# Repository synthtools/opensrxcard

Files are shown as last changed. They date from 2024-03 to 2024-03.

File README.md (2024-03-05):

# opensrxcard
opensrxcard is an open source SRX card project that consists of 
- An SRX card that can be used in Roland devices like the Fantom X/XR (other 5V devices like XV5080/XV3080 etc. in the future)
- An Arudino Due based programmer that allows to dump, program and erase SRX cards.





This is work in progress. Keep watching.

# Further information and documentation
Please go to the [wiki for detailed documentation](https://github.com/synthtools/opensrxcard/wiki).

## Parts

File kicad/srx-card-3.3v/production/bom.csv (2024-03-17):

Designator | Footprint | Quantity | Value | LCSC Part #
C1, C3, C7, C8 | 0805 | 4 | 100nF | C710699
C10 | CP_EIA-3528-21_Kemet-B_Pad1.50x2.35mm_HandSolder | 1 | Tantalum J106 10uF | C110050
C2, C4 | 0805 | 2 | 10nF | C161252
C9 | CP_EIA-3528-21_Kemet-B_Pad1.50x2.35mm_HandSolder | 1 | Tantalum J106 10uF | C110050
IC1, IC2 | TSOP-I-56_18.4x14mm_P0.5mm | 2 | MT28EW128ABA | C598856
R1 | 0805 | 1 | 100k | C122537
R2, R3, R4, R5 | 0805 | 4 | 10k | C441955

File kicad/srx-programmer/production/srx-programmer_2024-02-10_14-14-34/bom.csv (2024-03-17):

Designator | Footprint | Quantity | Value | LCSC Part #
C1 | CP_EIA-3216-12_Kemet-S_Pad1.58x1.35mm_HandSolder | 1 | Tantalum J104 0.1uF
J1 | PinHeader_1x08_P2.54mm_Vertical | 1 | Power
J2 | PinHeader_1x10_P2.54mm_Vertical | 1 | PWM
J3, J5 | PinHeader_1x08_P2.54mm_Vertical | 2 | Analog
J4 | PinHeader_1x08_P2.54mm_Vertical | 1 | PWM
J6 | PinHeader_1x08_P2.54mm_Vertical | 1 | Communication
J7 | PinHeader_2x18_P2.54mm_Vertical | 1 | Digital
J8 | JAE_TX25-80P-6ST-H1E | 1 | TX25-80P-6ST-H1E
J9 | PinHeader_2x02_P2.54mm_Vertical | 1 | Secondary Programming Connector
SW1, SW2, SW3 | SW_PUSH_6mm | 3 | SW_Push

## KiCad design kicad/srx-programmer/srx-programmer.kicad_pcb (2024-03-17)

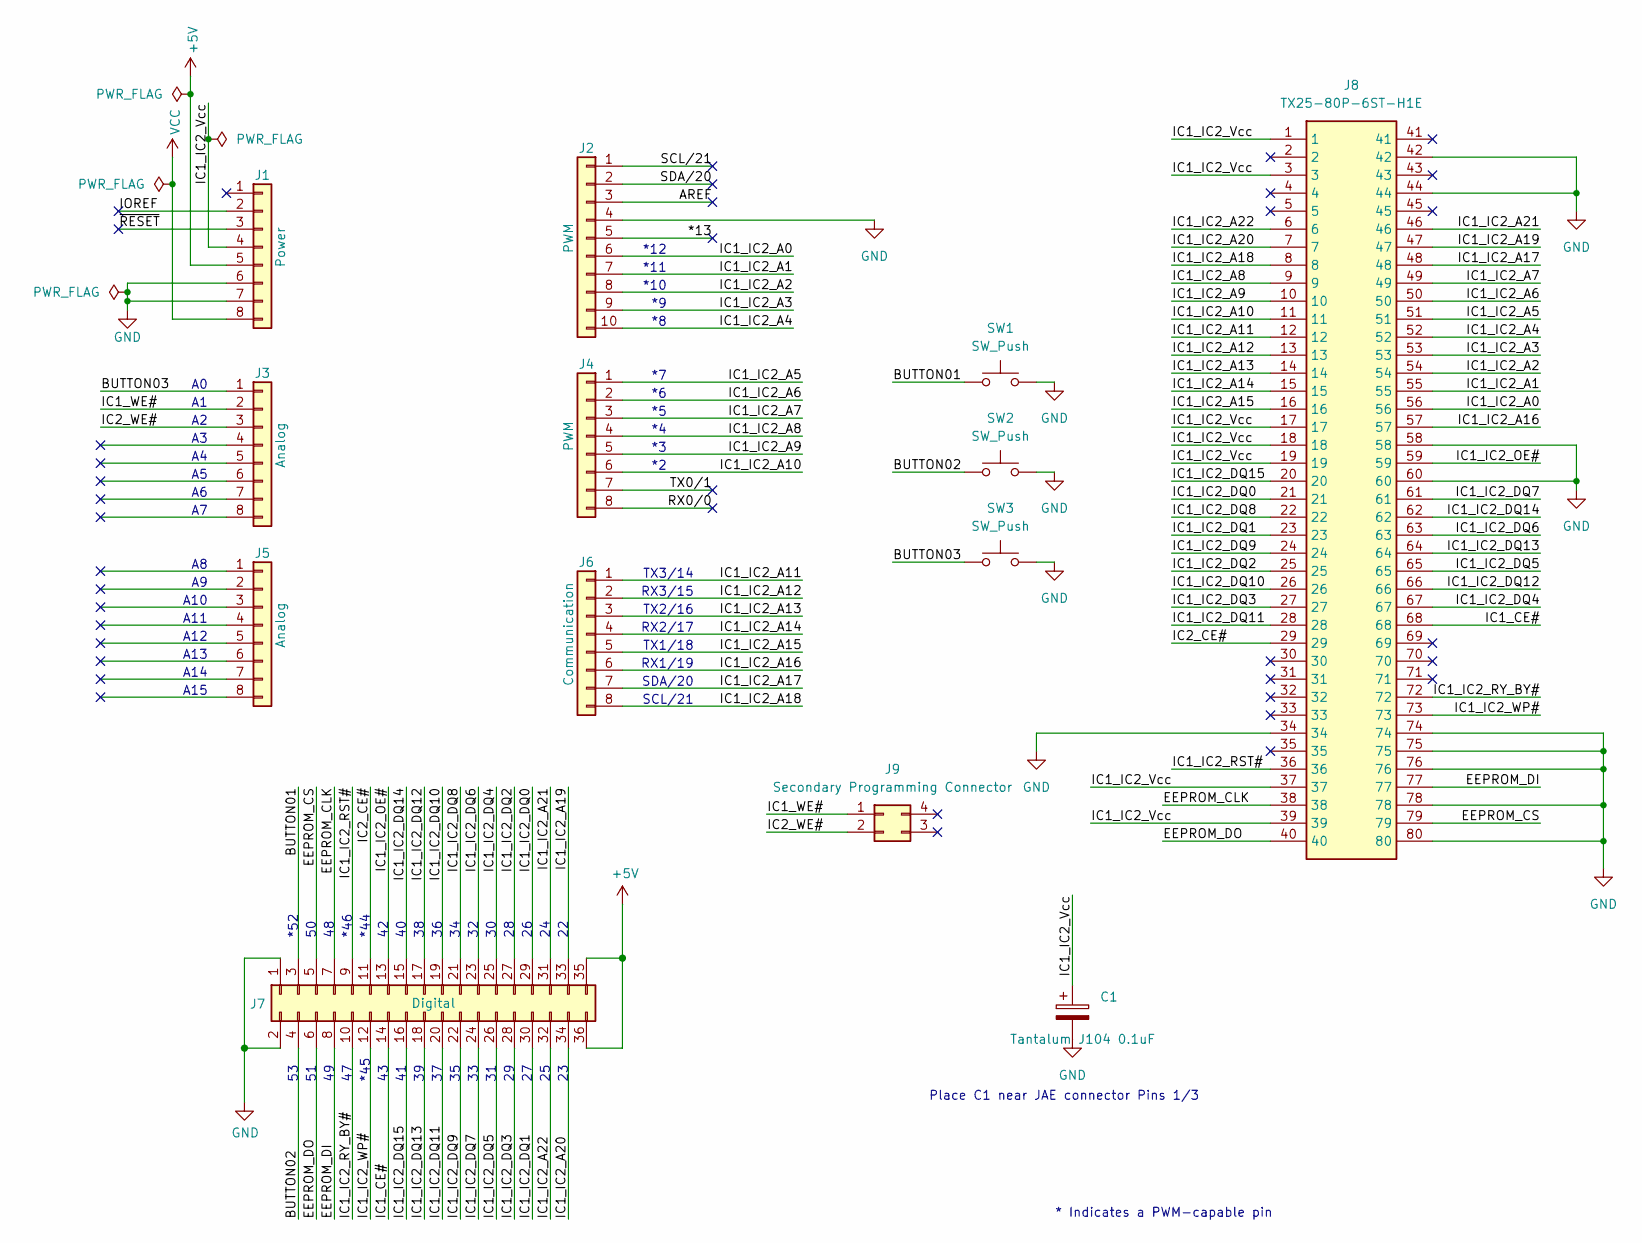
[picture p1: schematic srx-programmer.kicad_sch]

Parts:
C1: Tantalum J104 0.1uF; CP_EIA-3216-12_Kemet-S_Pad1.58x1.35mm_HandSolder
J1: Power; PinHeader_1x08_P2.54mm_Vertical
J2: PWM; PinHeader_1x10_P2.54mm_Vertical
J3, J5: Analog; PinHeader_1x08_P2.54mm_Vertical
J4: PWM; PinHeader_1x08_P2.54mm_Vertical
J6: Communication; PinHeader_1x08_P2.54mm_Vertical
J7: Digital; PinHeader_2x18_P2.54mm_Vertical
J8: TX25-80P-6ST-H1E; JAE_TX25-80P-6ST-H1E; Mouser Part Number 656-TX2580P6STH1E
J9: Secondary Programming Connector; PinHeader_2x02_P2.54mm_Vertical
SW1, SW2, SW3: SW_Push; SW_PUSH_6mm

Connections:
+5V: J1.5, J7.35, J7.36
/*13: J2.5
/AREF: J2.3
/BUTTON01: J7.3, SW1.1
/BUTTON02: J7.4, SW2.1
/BUTTON03: J3.1, SW3.1
/EEPROM_CLK: J7.7, J8.38
/EEPROM_CS: J7.5, J8.79
/EEPROM_DI: J7.8, J8.77
/EEPROM_DO: J7.6, J8.40
/IC1_CE#: J7.14, J8.68
/IC1_IC2_A0: J2.6, J8.56
/IC1_IC2_A1: J2.7, J8.55
/IC1_IC2_A2: J2.8, J8.54
/IC1_IC2_A3: J2.9, J8.53
/IC1_IC2_A4: J2.10, J8.52
/IC1_IC2_A5: J4.1, J8.51
/IC1_IC2_A6: J4.2, J8.50
/IC1_IC2_A7: J4.3, J8.49
/IC1_IC2_A8: J4.4, J8.9
/IC1_IC2_A9: J4.5, J8.10
/IC1_IC2_A10: J4.6, J8.11
/IC1_IC2_A11: J6.1, J8.12
/IC1_IC2_A12: J6.2, J8.13
/IC1_IC2_A13: J6.3, J8.14
/IC1_IC2_A14: J6.4, J8.15
/IC1_IC2_A15: J6.5, J8.16
/IC1_IC2_A16: J6.6, J8.57
/IC1_IC2_A17: J6.7, J8.48
/IC1_IC2_A18: J6.8, J8.8
/IC1_IC2_A19: J7.33, J8.47
/IC1_IC2_A20: J7.34, J8.7
/IC1_IC2_A21: J7.31, J8.46
/IC1_IC2_A22: J7.32, J8.6
/IC1_IC2_DQ0: J7.29, J8.21
/IC1_IC2_DQ1: J7.30, J8.23
/IC1_IC2_DQ2: J7.27, J8.25
/IC1_IC2_DQ3: J7.28, J8.27
/IC1_IC2_DQ4: J7.25, J8.67
/IC1_IC2_DQ5: J7.26, J8.65
/IC1_IC2_DQ6: J7.23, J8.63
/IC1_IC2_DQ7: J7.24, J8.61
/IC1_IC2_DQ8: J7.21, J8.22
/IC1_IC2_DQ9: J7.22, J8.24
/IC1_IC2_DQ10: J7.19, J8.26
/IC1_IC2_DQ11: J7.20, J8.28
/IC1_IC2_DQ12: J7.17, J8.66
/IC1_IC2_DQ13: J7.18, J8.64
/IC1_IC2_DQ14: J7.15, J8.62
/IC1_IC2_DQ15: J7.16, J8.20
/IC1_IC2_OE#: J7.13, J8.59
/IC1_IC2_RST#: J7.9, J8.36
/IC1_IC2_RY_BY#: J7.10, J8.72
/IC1_IC2_Vcc: C1.1, J1.4, J8.1, J8.3, J8.17, J8.18, J8.19, J8.37, J8.39
/IC1_IC2_WP#: J7.12, J8.73
/IC1_WE#: J3.2, J9.1
/IC2_CE#: J7.11, J8.29
/IC2_WE#: J3.3, J9.2
/IOREF: J1.2
/RX0/0: J4.8
/SCL/21: J2.1
/SDA/20: J2.2
/TX0/1: J4.7
/~RESET: J1.3
GND: C1.2, J1.6, J1.7, J2.4, J7.1, J7.2, J8.34, J8.42, J8.44, J8.58, J8.60, J8.74, J8.75, J8.76, J8.78, J8.80, SW1.2, SW2.2, SW3.2
VCC: J1.8

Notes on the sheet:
TX1/18
RX2/17
*12
SCL/21
TX2/16
A11
*44
RX3/15
*45
A10
A12
SDA/20
RX1/19
*11
Place C1 near JAE connector Pins 1/3
* Indicates a PWM-capable pin
*46
A15
*10
A14
A13
*52
TX3/14

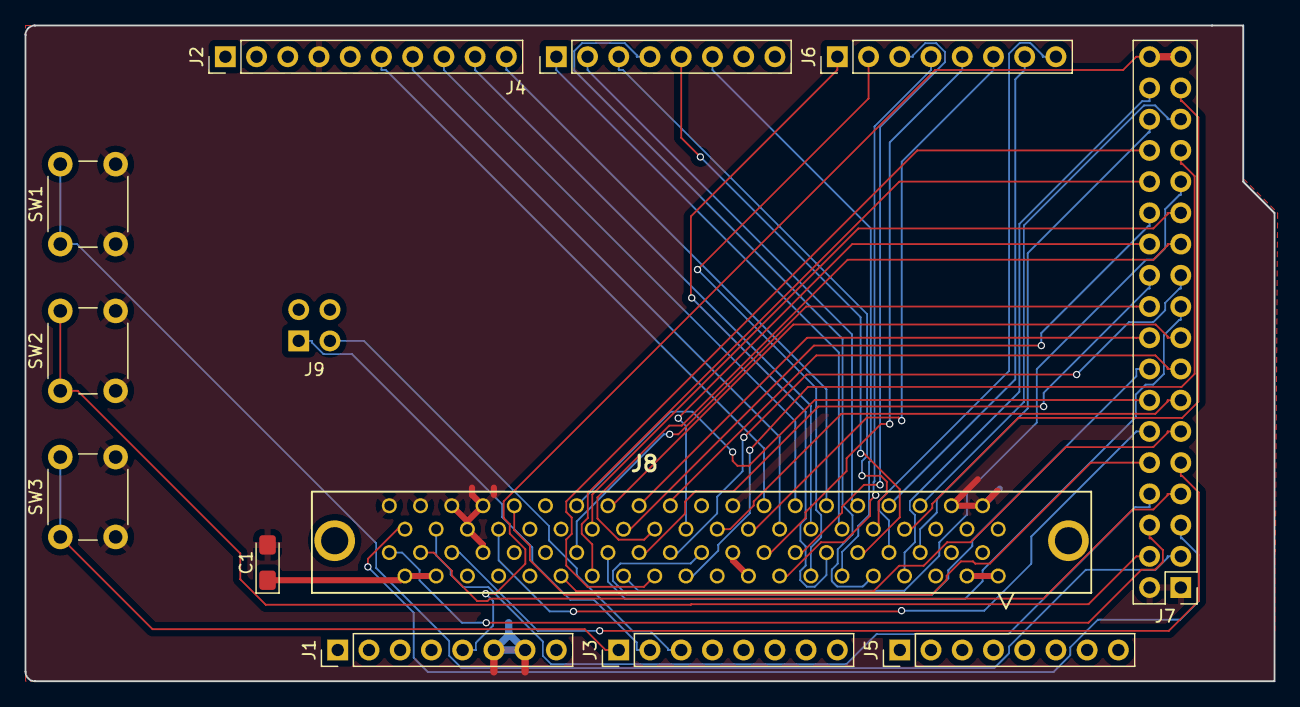
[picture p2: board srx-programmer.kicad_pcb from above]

Board: 4 copper layers, 101.6 x 53.3 mm, 13 parts (1 on the bottom side), 57 nets.

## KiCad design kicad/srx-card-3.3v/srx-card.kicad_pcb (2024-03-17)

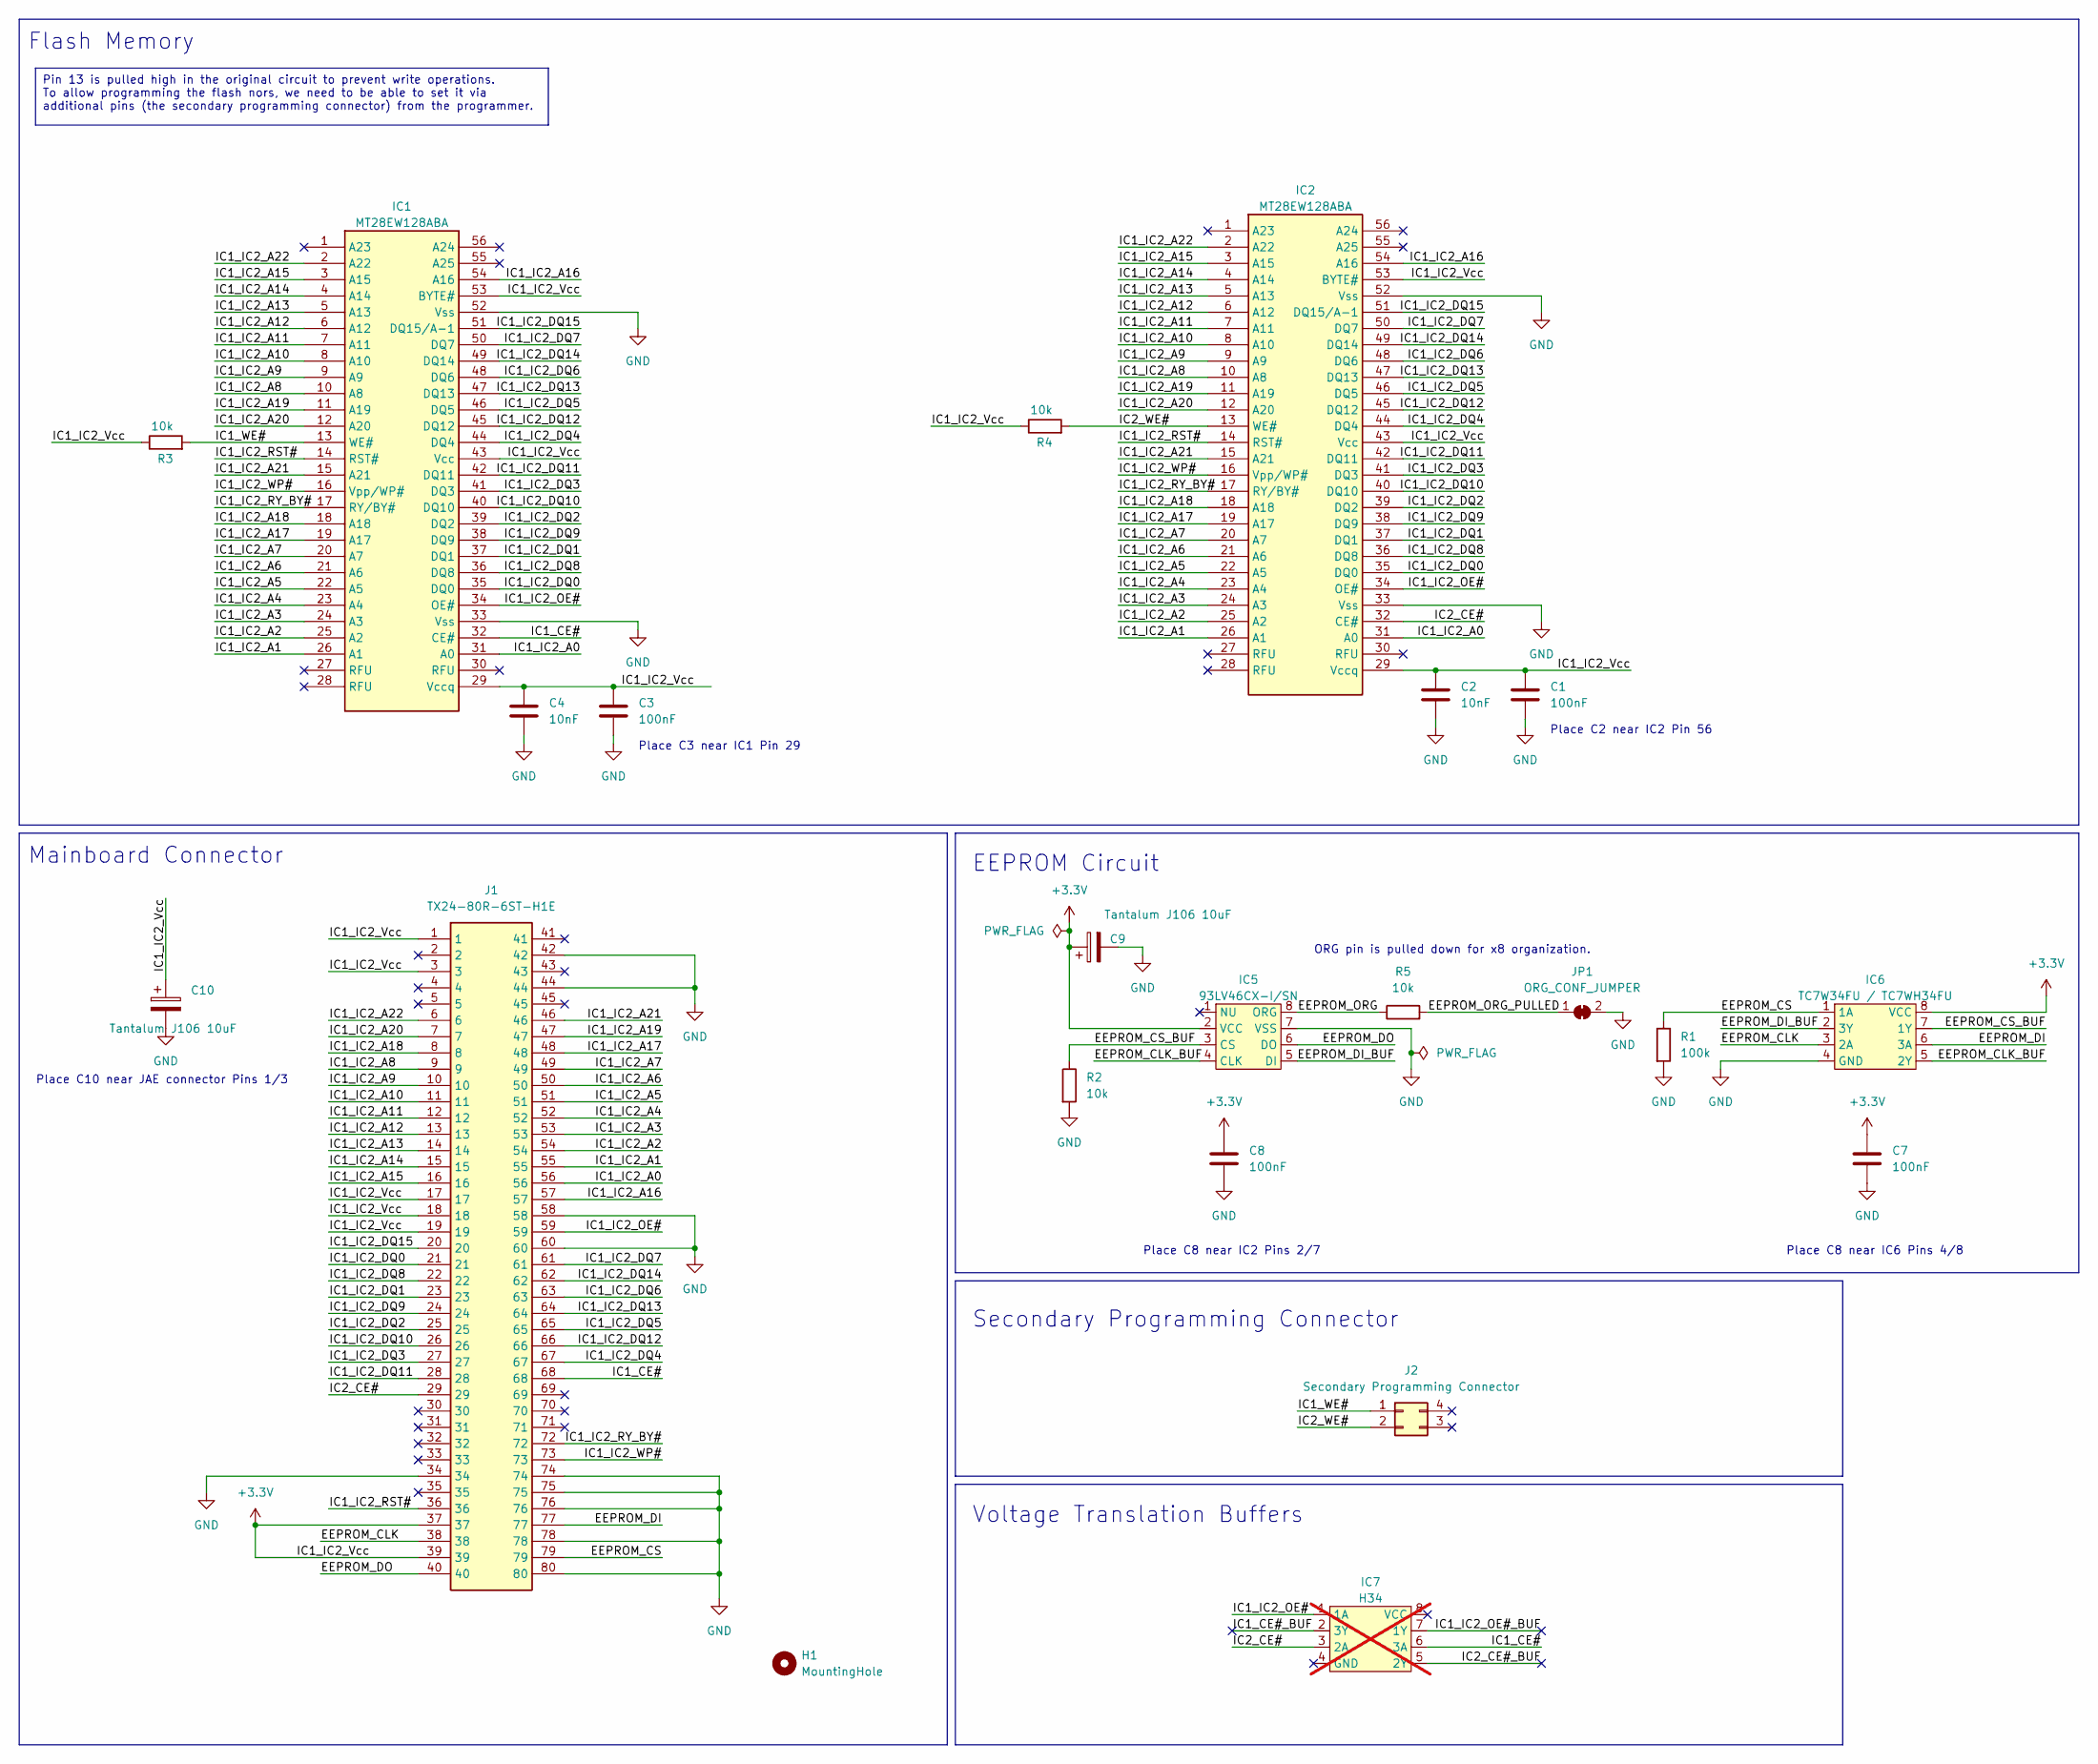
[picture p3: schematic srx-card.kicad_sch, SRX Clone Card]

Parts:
C1, C3, C7, C8: 100nF; C_0805_2012Metric_Pad1.18x1.45mm_HandSolder; LCSC C710699
C2, C4: 10nF; C_0805_2012Metric_Pad1.18x1.45mm_HandSolder; LCSC C161252
C9, C10: Tantalum J106 10uF; CP_EIA-3528-21_Kemet-B_Pad1.50x2.35mm_HandSolder; LCSC C110050
H1: MountingHole; MountingHole_5mm
IC1, IC2: MT28EW128ABA; TSOP-I-56_18.4x14mm_P0.5mm; LCSC C598856
IC5: 93LV46CX-I/SN; SOIC-8_3.9x4.9mm_P1.27mm
IC6: TC7W34FU / TC7WH34FU; SSOP-8_2.95x2.8mm_P0.65mm; LCSC C2676253
IC7: H34; SSOP-8_2.95x2.8mm_P0.65mm; not fitted
J1: TX24-80R-6ST-H1E; JAE_TX24-80R-6ST-H1E; Mouser Part Number 656-TX24-80R-6ST-H1E
J2: Secondary Programming Connector; PinHeader_2x02_P2.54mm_Vertical
JP1: ORG_CONF_JUMPER; SolderJumper-2_P1.3mm_Bridged_Pad1.0x1.5mm
R1: 100k; R_0805_2012Metric_Pad1.20x1.40mm_HandSolder; LCSC C122537
R2, R3, R4, R5: 10k; R_0805_2012Metric_Pad1.20x1.40mm_HandSolder; LCSC C441955

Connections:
+3.3V: C1.1, C2.1, C3.1, C4.1, C7.1, C8.1, C9.1, C10.1, IC1.29 (Vccq), IC1.43 (Vcc), IC1.53 (BYTE#), IC2.29 (Vccq), IC2.43 (Vcc), IC2.53 (BYTE#), IC5.2 (VCC), IC6.8 (VCC), J1.1, J1.3, J1.17, J1.18, J1.19, J1.37, J1.39, R3.1, R4.1
/EEPROM_CLK: IC6.3 (2A), J1.38
/EEPROM_CLK_BUF: IC5.4 (CLK), IC6.5 (2Y)
/EEPROM_CS: IC6.1 (1A), J1.79, R1.1
/EEPROM_CS_BUF: IC5.3 (CS), IC6.7 (1Y), R2.1
/EEPROM_DI: IC6.6 (3A), J1.77
/EEPROM_DI_BUF: IC5.5 (DI), IC6.2 (3Y)
/EEPROM_DO: IC5.6 (DO), J1.40
/EEPROM_ORG: IC5.8 (ORG), R5.1
/EEPROM_ORG_PULLED: JP1.1 (A), R5.2
/IC1_CE#: IC1.32 (CE#), IC7.6 (3A), J1.68
/IC1_IC2_A0: IC1.31 (A0), IC2.31 (A0), J1.56
/IC1_IC2_A1: IC1.26 (A1), IC2.26 (A1), J1.55
/IC1_IC2_A2: IC1.25 (A2), IC2.25 (A2), J1.54
/IC1_IC2_A3: IC1.24 (A3), IC2.24 (A3), J1.53
/IC1_IC2_A4: IC1.23 (A4), IC2.23 (A4), J1.52
/IC1_IC2_A5: IC1.22 (A5), IC2.22 (A5), J1.51
/IC1_IC2_A6: IC1.21 (A6), IC2.21 (A6), J1.50
/IC1_IC2_A7: IC1.20 (A7), IC2.20 (A7), J1.49
/IC1_IC2_A8: IC1.10 (A8), IC2.10 (A8), J1.9
/IC1_IC2_A9: IC1.9 (A9), IC2.9 (A9), J1.10
/IC1_IC2_A10: IC1.8 (A10), IC2.8 (A10), J1.11
/IC1_IC2_A11: IC1.7 (A11), IC2.7 (A11), J1.12
/IC1_IC2_A12: IC1.6 (A12), IC2.6 (A12), J1.13
/IC1_IC2_A13: IC1.5 (A13), IC2.5 (A13), J1.14
/IC1_IC2_A14: IC1.4 (A14), IC2.4 (A14), J1.15
/IC1_IC2_A15: IC1.3 (A15), IC2.3 (A15), J1.16
/IC1_IC2_A16: IC1.54 (A16), IC2.54 (A16), J1.57
/IC1_IC2_A17: IC1.19 (A17), IC2.19 (A17), J1.48
/IC1_IC2_A18: IC1.18 (A18), IC2.18 (A18), J1.8
/IC1_IC2_A19: IC1.11 (A19), IC2.11 (A19), J1.47
/IC1_IC2_A20: IC1.12 (A20), IC2.12 (A20), J1.7
/IC1_IC2_A21: IC1.15 (A21), IC2.15 (A21), J1.46
/IC1_IC2_A22: IC1.2 (A22), IC2.2 (A22), J1.6
/IC1_IC2_DQ0: IC1.35 (DQ0), IC2.35 (DQ0), J1.21
/IC1_IC2_DQ1: IC1.37 (DQ1), IC2.37 (DQ1), J1.23
/IC1_IC2_DQ2: IC1.39 (DQ2), IC2.39 (DQ2), J1.25
/IC1_IC2_DQ3: IC1.41 (DQ3), IC2.41 (DQ3), J1.27
/IC1_IC2_DQ4: IC1.44 (DQ4), IC2.44 (DQ4), J1.67
/IC1_IC2_DQ5: IC1.46 (DQ5), IC2.46 (DQ5), J1.65
/IC1_IC2_DQ6: IC1.48 (DQ6), IC2.48 (DQ6), J1.63
/IC1_IC2_DQ7: IC1.50 (DQ7), IC2.50 (DQ7), J1.61
/IC1_IC2_DQ8: IC1.36 (DQ8), IC2.36 (DQ8), J1.22
/IC1_IC2_DQ9: IC1.38 (DQ9), IC2.38 (DQ9), J1.24
/IC1_IC2_DQ10: IC1.40 (DQ10), IC2.40 (DQ10), J1.26
/IC1_IC2_DQ11: IC1.42 (DQ11), IC2.42 (DQ11), J1.28
/IC1_IC2_DQ12: IC1.45 (DQ12), IC2.45 (DQ12), J1.66
/IC1_IC2_DQ13: IC1.47 (DQ13), IC2.47 (DQ13), J1.64
/IC1_IC2_DQ14: IC1.49 (DQ14), IC2.49 (DQ14), J1.62
/IC1_IC2_DQ15: IC1.51 (DQ15/A-1), IC2.51 (DQ15/A-1), J1.20
/IC1_IC2_OE#: IC1.34 (OE#), IC2.34 (OE#), IC7.1 (1A), J1.59
/IC1_IC2_RST#: IC1.14 (RST#), IC2.14 (RST#), J1.36
/IC1_IC2_RY_BY#: IC1.17 (RY/BY#), IC2.17 (RY/BY#), J1.72
/IC1_IC2_WP#: IC1.16 (Vpp/WP#), IC2.16 (Vpp/WP#), J1.73
/IC1_WE#: IC1.13 (WE#), J2.1, R3.2
/IC2_CE#: IC2.32 (CE#), IC7.3 (2A), J1.29
/IC2_WE#: IC2.13 (WE#), J2.2, R4.2
GND: C1.2, C2.2, C3.2, C4.2, C7.2, C8.2, C9.2, C10.2, IC1.33 (Vss), IC1.52 (Vss), IC2.33 (Vss), IC2.52 (Vss), IC5.7 (VSS), IC6.4 (GND), J1.34, J1.42, J1.44, J1.58, J1.60, J1.74, J1.75, J1.76, J1.78, J1.80, JP1.2 (B), R1.2, R2.2

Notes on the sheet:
Pin 13 is pulled high in the original circuit to prevent write operations. To allow programming the flash nors, we need to be able to set it via additional pins (the secondary programming connector) from the programmer.
Flash Memory
Place C3 near IC1 Pin 29
Place C10 near JAE connector Pins 1/3
Place C2 near IC2 Pin 56
ORG pin is pulled down for x8 organization.
Voltage Translation Buffers
EEPROM Circuit
Place C8 near IC6 Pins 4/8
Place C8 near IC2 Pins 2/7
Secondary Programming Connector
Mainboard Connector

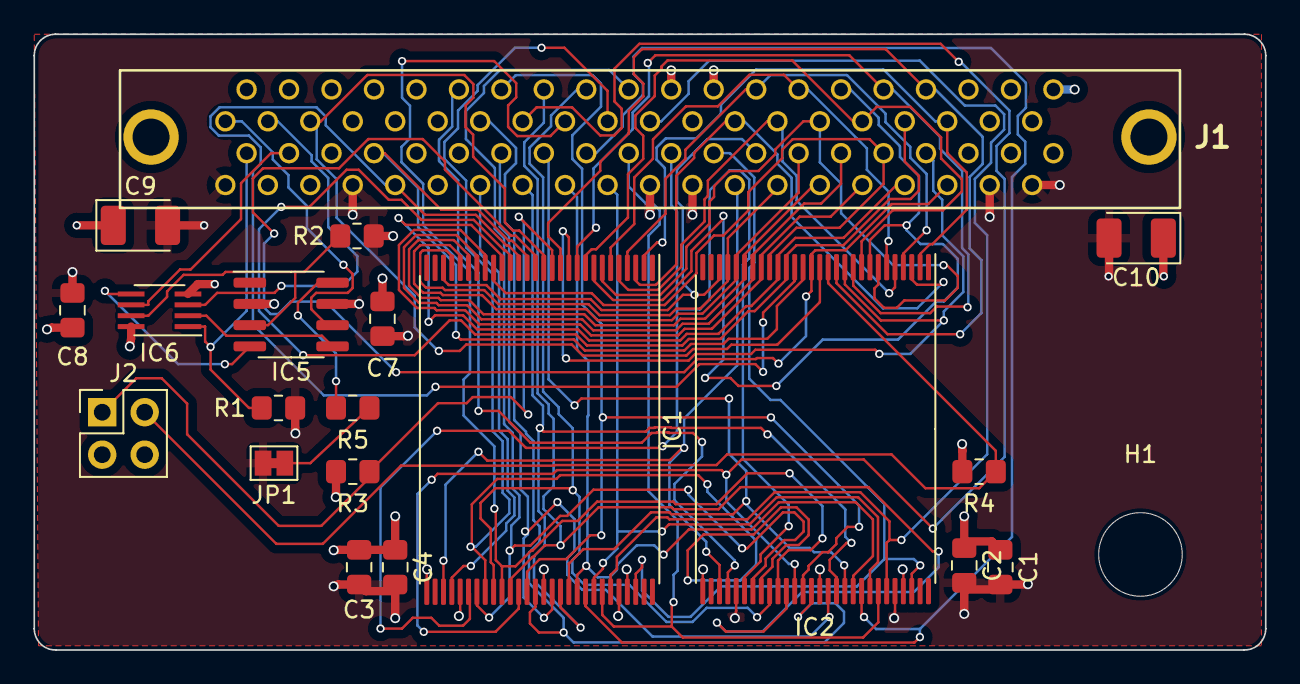
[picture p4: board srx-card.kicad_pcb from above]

Board: 4 copper layers, 73.7 x 36.8 mm, 21 parts (0 on the bottom side), 58 nets.

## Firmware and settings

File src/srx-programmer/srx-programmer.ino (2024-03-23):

#define FLASH_A00 12
#define FLASH_A01 11
#define FLASH_A02 10
#define FLASH_A03 9
#define FLASH_A04 8
#define FLASH_A05 7
#define FLASH_A06 6
#define FLASH_A07 5
#define FLASH_A08 4
#define FLASH_A09 3
#define FLASH_A10 2
#define FLASH_A11 14
#define FLASH_A12 15
#define FLASH_A13 16
#define FLASH_A14 17
#define FLASH_A15 18
#define FLASH_A16 19
#define FLASH_A17 20
#define FLASH_A18 21
#define FLASH_A19 23
#define FLASH_A20 22
#define FLASH_A21 25
#define FLASH_A22 24

#define FLASH_DQ00 27
#define FLASH_DQ01 26
#define FLASH_DQ02 29
#define FLASH_DQ03 28
#define FLASH_DQ04 31
#define FLASH_DQ05 30
#define FLASH_DQ06 33
#define FLASH_DQ07 32
#define FLASH_DQ08 35
#define FLASH_DQ09 34
#define FLASH_DQ10 37
#define FLASH_DQ11 36
#define FLASH_DQ12 39
#define FLASH_DQ13 38
#define FLASH_DQ14 41
#define FLASH_DQ15 40

#define FLASH_OE_n 43
#define FLASH_IC1_CE_n 42
#define FLASH_IC2_CE_n 45
#define FLASH_WP_n 44
#define FLASH_RST_n 47
#define FLASH_RY_BY 46
/*
#define EEPROM_CLK 49
#define EEPROM_DI 48
#define EEPROM_CS 51
#define EEPROM_DO 50
*/
#define BUTTON01 53
#define BUTTON02 52
#define BUTTON03 A0
#define IC1_WE_n A1
#define IC2_WE_n A2

#define BAUD_RATE 115200
//#define BAUD_RATE 57600

#define FLASH_PROGMEM
#define FLASH_READ_DWORD(x) (*(uint32_t *)(x))

#define BLOCK_SIZE 512

const uint32_t INITIAL_VALUE = ~0L;

static const uint32_t crc32_table[] FLASH_PROGMEM = {
  0x00000000, 0x1db71064, 0x3b6e20c8, 0x26d930ac,
  0x76dc4190, 0x6b6b51f4, 0x4db26158, 0x5005713c,
  0xedb88320, 0xf00f9344, 0xd6d6a3e8, 0xcb61b38c,
  0x9b64c2b0, 0x86d3d2d4, 0xa00ae278, 0xbdbdf21c
};

// ---------------------------------------------------------------------------------------------------------

uint32_t updateCRC32(uint8_t data, uint32_t _state) {
  uint8_t tbl_idx = 0;

  tbl_idx = _state ^ (data >> (0 * 4));
  _state = FLASH_READ_DWORD(crc32_table + (tbl_idx & 0x0f)) ^ (_state >> 4);
  tbl_idx = _state ^ (data >> (1 * 4));
  _state = FLASH_READ_DWORD(crc32_table + (tbl_idx & 0x0f)) ^ (_state >> 4);

  return _state;
}

// ---------------------------------------------------------------------------------------------------------

int display_progress_bar(unsigned int current, unsigned int total, int last_value) {
  // Calculate the percentage completed
  int percentage = (int)(((float)current / (float)total) * 100);
  // Determine the size of the progress bar
  int size = 50;  // Number of characters in the progress bar

  // Calculate how many characters should be filled
  int filled = (percentage * size) / 100;

  // Build the progress bar string
  String progressBar = "[";
  for (int i = 0; i < filled; i++) {
    progressBar += "=";
  }
  for (int i = filled; i < size; i++) {
    progressBar += " ";
  }
  progressBar += "] ";

  // Print the progress bar and percentage
  if ((last_value == -1) || (last_value != percentage)) {
    SerialUSB.print(progressBar);
    SerialUSB.print(percentage);
    SerialUSB.println("%");
  }

  return percentage;
}

// ---------------------------------------------------------------------------------------------------------

String pad_str(uint32_t sourceStr, int padWidth) {
  String inputStr = String(sourceStr, HEX);
  inputStr.toUpperCase();

  while (inputStr.length() < padWidth) {
    inputStr = "0" + inputStr;
  }

  return inputStr;
}

// ---------------------------------------------------------------------------------------------------------

void setup() {
  pinMode(LED_BUILTIN, OUTPUT);
  pinMode(FLASH_A00, OUTPUT);
  pinMode(FLASH_A01, OUTPUT);
  pinMode(FLASH_A02, OUTPUT);
  pinMode(FLASH_A03, OUTPUT);
  pinMode(FLASH_A04, OUTPUT);
  pinMode(FLASH_A05, OUTPUT);
  pinMode(FLASH_A06, OUTPUT);
  pinMode(FLASH_A07, OUTPUT);
  pinMode(FLASH_A08, OUTPUT);
  pinMode(FLASH_A09, OUTPUT);
  pinMode(FLASH_A10, OUTPUT);
  pinMode(FLASH_A11, OUTPUT);
  pinMode(FLASH_A12, OUTPUT);
  pinMode(FLASH_A13, OUTPUT);
  pinMode(FLASH_A14, OUTPUT);
  pinMode(FLASH_A15, OUTPUT);
  pinMode(FLASH_A16, OUTPUT);
  pinMode(FLASH_A17, OUTPUT);
  pinMode(FLASH_A18, OUTPUT);
  pinMode(FLASH_A19, OUTPUT);
  pinMode(FLASH_A20, OUTPUT);
  pinMode(FLASH_A21, OUTPUT);
  pinMode(FLASH_A22, OUTPUT);
  init_address_pins();
/*  
  pinMode(FLASH_DQ00, INPUT);pinMode(FLASH_DQ01, INPUT);pinMode(FLASH_DQ02, INPUT);
  pinMode(FLASH_DQ03, INPUT);pinMode(FLASH_DQ04, INPUT);pinMode(FLASH_DQ05, INPUT);
  pinMode(FLASH_DQ06, INPUT);pinMode(FLASH_DQ07, INPUT);pinMode(FLASH_DQ08, INPUT);
  pinMode(FLASH_DQ09, INPUT);pinMode(FLASH_DQ10, INPUT);pinMode(FLASH_DQ11, INPUT);
  pinMode(FLASH_DQ12, INPUT);pinMode(FLASH_DQ13, INPUT);pinMode(FLASH_DQ14, INPUT);
  pinMode(FLASH_DQ15, INPUT);
*/
  pinMode(BUTTON01, INPUT_PULLUP);
  pinMode(BUTTON02, INPUT_PULLUP);
  pinMode(BUTTON03, INPUT_PULLUP);

  pinMode(FLASH_OE_n, OUTPUT);
  pinMode(FLASH_IC1_CE_n, OUTPUT);
  pinMode(FLASH_IC2_CE_n, OUTPUT);
  pinMode(FLASH_WP_n, OUTPUT);
  pinMode(FLASH_RST_n, OUTPUT);
  pinMode(FLASH_RY_BY, INPUT);
  /*
  pinMode(EEPROM_CLK, OUTPUT);
  pinMode(EEPROM_DI, INPUT);
  pinMode(EEPROM_CS, OUTPUT);
  pinMode(EEPROM_DO, OUTPUT);
*/
  pinMode(IC1_WE_n, OUTPUT);
  pinMode(IC2_WE_n, OUTPUT);

  // write protect on initialization
  digitalWrite(IC1_WE_n, HIGH);
  digitalWrite(IC2_WE_n, HIGH);

  // no chip enabled by default
  digitalWrite(FLASH_IC1_CE_n, HIGH);
  digitalWrite(FLASH_IC2_CE_n, HIGH);

  // OE inactive on initialization
  digitalWrite(FLASH_OE_n, HIGH);

  // reset the chip
  digitalWrite(FLASH_RST_n, HIGH);
  delay(10);
  digitalWrite(FLASH_RST_n, LOW);
  delay(10);
  digitalWrite(FLASH_RST_n, HIGH);

  Serial.begin(BAUD_RATE);
  SerialUSB.begin(BAUD_RATE);

  while (!SerialUSB) {
  }
}

// ---------------------------------------------------------------------------------------------------------

void configure_datapins_read() {
  pinMode(FLASH_DQ00, INPUT);
  pinMode(FLASH_DQ01, INPUT);
  pinMode(FLASH_DQ02, INPUT);
  pinMode(FLASH_DQ03, INPUT);
  pinMode(FLASH_DQ04, INPUT);
  pinMode(FLASH_DQ05, INPUT);
  pinMode(FLASH_DQ06, INPUT);
  pinMode(FLASH_DQ07, INPUT);
  pinMode(FLASH_DQ08, INPUT);
  pinMode(FLASH_DQ09, INPUT);
  pinMode(FLASH_DQ10, INPUT);
  pinMode(FLASH_DQ11, INPUT);
  pinMode(FLASH_DQ12, INPUT);
  pinMode(FLASH_DQ13, INPUT);
  pinMode(FLASH_DQ14, INPUT);
  pinMode(FLASH_DQ15, INPUT);
}

// ---------------------------------------------------------------------------------------------------------

void configure_datapins_write() {
  pinMode(FLASH_DQ00, OUTPUT);
  pinMode(FLASH_DQ01, OUTPUT);
  pinMode(FLASH_DQ02, OUTPUT);
  pinMode(FLASH_DQ03, OUTPUT);
  pinMode(FLASH_DQ04, OUTPUT);
  pinMode(FLASH_DQ05, OUTPUT);
  pinMode(FLASH_DQ06, OUTPUT);
  pinMode(FLASH_DQ07, OUTPUT);
  pinMode(FLASH_DQ08, OUTPUT);
  pinMode(FLASH_DQ09, OUTPUT);
  pinMode(FLASH_DQ10, OUTPUT);
  pinMode(FLASH_DQ11, OUTPUT);
  pinMode(FLASH_DQ12, OUTPUT);
  pinMode(FLASH_DQ13, OUTPUT);
  pinMode(FLASH_DQ14, OUTPUT);
  pinMode(FLASH_DQ15, OUTPUT);
}

// ---------------------------------------------------------------------------------------------------------

void init_address_pins() {
  int init_state = LOW;
  digitalWrite(FLASH_A00, init_state);
  digitalWrite(FLASH_A01, init_state);
  digitalWrite(FLASH_A02, init_state);
  digitalWrite(FLASH_A03, init_state);
  digitalWrite(FLASH_A04, init_state);
  digitalWrite(FLASH_A05, init_state);
  digitalWrite(FLASH_A06, init_state);
  digitalWrite(FLASH_A07, init_state);
  digitalWrite(FLASH_A08, init_state);
  digitalWrite(FLASH_A09, init_state);
  digitalWrite(FLASH_A10, init_state);
  digitalWrite(FLASH_A11, init_state);
  digitalWrite(FLASH_A12, init_state);
  digitalWrite(FLASH_A13, init_state);
  digitalWrite(FLASH_A14, init_state);
  digitalWrite(FLASH_A15, init_state);
  digitalWrite(FLASH_A16, init_state);
  digitalWrite(FLASH_A17, init_state);
  digitalWrite(FLASH_A18, init_state);
  digitalWrite(FLASH_A19, init_state);
  digitalWrite(FLASH_A20, init_state);
  digitalWrite(FLASH_A21, init_state);
  digitalWrite(FLASH_A22, init_state);
}

// ---------------------------------------------------------------------------------------------------------

uint16_t read_data(uint32_t address) {
  digitalWrite(FLASH_A00, (address >> 0) & 1);
  digitalWrite(FLASH_A01, (address >> 1) & 1);
  digitalWrite(FLASH_A02, (address >> 2) & 1);
  digitalWrite(FLASH_A03, (address >> 3) & 1);
  digitalWrite(FLASH_A04, (address >> 4) & 1);
  digitalWrite(FLASH_A05, (address >> 5) & 1);
  digitalWrite(FLASH_A06, (address >> 6) & 1);
  digitalWrite(FLASH_A07, (address >> 7) & 1);
  digitalWrite(FLASH_A08, (address >> 8) & 1);
  digitalWrite(FLASH_A09, (address >> 9) & 1);
  digitalWrite(FLASH_A10, (address >> 10) & 1);
  digitalWrite(FLASH_A11, (address >> 11) & 1);
  digitalWrite(FLASH_A12, (address >> 12) & 1);
  digitalWrite(FLASH_A13, (address >> 13) & 1);
  digitalWrite(FLASH_A14, (address >> 14) & 1);
  digitalWrite(FLASH_A15, (address >> 15) & 1);
  digitalWrite(FLASH_A16, (address >> 16) & 1);
  digitalWrite(FLASH_A17, (address >> 17) & 1);
  digitalWrite(FLASH_A18, (address >> 18) & 1);
  digitalWrite(FLASH_A19, (address >> 19) & 1);
  digitalWrite(FLASH_A20, (address >> 20) & 1);
  digitalWrite(FLASH_A21, (address >> 21) & 1);
  digitalWrite(FLASH_A22, (address >> 22) & 1);

  delayMicroseconds(1);
  digitalWrite(FLASH_OE_n, LOW);
  delayMicroseconds(1);

  uint16_t data = 0;

  data |= digitalRead(FLASH_DQ00) << 0;
  data |= digitalRead(FLASH_DQ01) << 1;
  data |= digitalRead(FLASH_DQ02) << 2;
  data |= digitalRead(FLASH_DQ03) << 3;
  data |= digitalRead(FLASH_DQ04) << 4;
  data |= digitalRead(FLASH_DQ05) << 5;
  data |= digitalRead(FLASH_DQ06) << 6;
  data |= digitalRead(FLASH_DQ07) << 7;
  data |= digitalRead(FLASH_DQ08) << 8;
  data |= digitalRead(FLASH_DQ09) << 9;
  data |= digitalRead(FLASH_DQ10) << 10;
  data |= digitalRead(FLASH_DQ11) << 11;
  data |= digitalRead(FLASH_DQ12) << 12;
  data |= digitalRead(FLASH_DQ13) << 13;
  data |= digitalRead(FLASH_DQ14) << 14;
  data |= digitalRead(FLASH_DQ15) << 15;

  digitalWrite(FLASH_OE_n, HIGH);
  delayMicroseconds(1);

  return data;
}

// ---------------------------------------------------------------------------------------------------------

uint16_t read_data_same_address() {
  digitalWrite(FLASH_OE_n, LOW);
  delayMicroseconds(1);

  uint16_t data = 0;

  data |= digitalRead(FLASH_DQ00) << 0;
  data |= digitalRead(FLASH_DQ01) << 1;
  data |= digitalRead(FLASH_DQ02) << 2;
  data |= digitalRead(FLASH_DQ03) << 3;
  data |= digitalRead(FLASH_DQ04) << 4;
  data |= digitalRead(FLASH_DQ05) << 5;
  data |= digitalRead(FLASH_DQ06) << 6;
  data |= digitalRead(FLASH_DQ07) << 7;
  data |= digitalRead(FLASH_DQ08) << 8;
  data |= digitalRead(FLASH_DQ09) << 9;
  data |= digitalRead(FLASH_DQ10) << 10;
  data |= digitalRead(FLASH_DQ11) << 11;
  data |= digitalRead(FLASH_DQ12) << 12;
  data |= digitalRead(FLASH_DQ13) << 13;
  data |= digitalRead(FLASH_DQ14) << 14;
  data |= digitalRead(FLASH_DQ15) << 15;

  digitalWrite(FLASH_OE_n, HIGH);
  delayMicroseconds(1);

  return data;
}

// ---------------------------------------------------------------------------------------------------------

bool read_data_same_address_dq07() {
  digitalWrite(FLASH_OE_n, LOW);
  delayMicroseconds(1);

  bool data = false;

  data = (bool) digitalRead(FLASH_DQ07) << 7;

  digitalWrite(FLASH_OE_n, HIGH);
  delayMicroseconds(1);

  return data;
}

// ---------------------------------------------------------------------------------------------------------
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
void loop() {
  static String inputString = "";         // a String to hold incoming data
  static boolean stringComplete = false;  // whether the string is complete

  static unsigned long lastDebounceTime01 = 0;
  static unsigned long lastDebounceTime02 = 0;
  static unsigned long lastDebounceTime03 = 0;
  bool lastButton01State = HIGH;
  bool lastButton02State = HIGH;
  bool lastButton03State = HIGH;
  unsigned long debounceDelay = 300;

  bool currentButton01State = digitalRead(BUTTON01);
  bool currentButton02State = digitalRead(BUTTON02);
  bool currentButton03State = digitalRead(BUTTON03);

  if ((lastButton01State == HIGH) && (currentButton01State == LOW) && ((millis() - lastDebounceTime01) > debounceDelay)) {
    SerialUSB.println("Button 01 pressed");
    lastDebounceTime01 = millis();
  }

  if ((lastButton02State == HIGH) && (currentButton02State == LOW) && ((millis() - lastDebounceTime02) > debounceDelay)) {
    SerialUSB.println("Button 02 pressed");
    lastDebounceTime02 = millis();
  }

  if ((lastButton03State == HIGH) && (currentButton03State == LOW) && ((millis() - lastDebounceTime03) > debounceDelay)) {
    SerialUSB.println("Button 03 pressed");
    lastDebounceTime03 = millis();
  }

  if (SerialUSB.available() > 0) {
    char inChar = SerialUSB.read();  // Read the incoming character
    if (inChar == '\n') {
      stringComplete = true;
    } else {
      // otherwise add it to the inputString:
      inputString += inChar;
    }
  }

  // check if the string is complete
  if (stringComplete) {
    inputString.trim();
    inputString.toLowerCase();
    // Check if the received character is 'V' or 'v'
    if (inputString.equals("v")) {
      // Send the version number back to the computer
      SerialUSB.println("Version 0.1");
    } else if (inputString.startsWith("hdp1 ")) {
      configure_datapins_read();
      digitalWrite(FLASH_OE_n, LOW);
      delayMicroseconds(100);

      // remove the command part ("hdp ")
      String args = inputString.substring(5);

      // find the space between the addresses
      int spaceIndex = args.indexOf(' ');
      if (spaceIndex != -1) {

        // parse the start address
        String startAddrStr = args.substring(0, spaceIndex);
        uint32_t startAddress = strtoul(startAddrStr.c_str(), NULL, 16);

        // parse the end address
        String endAddrStr = args.substring(spaceIndex + 1);
        uint32_t endAddress = strtoul(endAddrStr.c_str(), NULL, 16);

        digitalWrite(FLASH_IC1_CE_n, LOW);
        delayMicroseconds(100);

        // call the function to print the hex dump
        print_hex_dump(startAddress, endAddress);

        // reset chip enable pins
        digitalWrite(FLASH_IC1_CE_n, HIGH);
        delayMicroseconds(100);
        digitalWrite(FLASH_IC2_CE_n, HIGH);
        delayMicroseconds(100);
      }
    } else if (inputString.startsWith("hdp2 ")) {
      configure_datapins_read();
      digitalWrite(FLASH_OE_n, LOW);
      delayMicroseconds(100);
      // remove the command part ("hdp ")
      String args = inputString.substring(5);

      // find the space between the addresses
      int spaceIndex = args.indexOf(' ');
      if (spaceIndex != -1) {

        // parse the start address
        String startAddrStr = args.substring(0, spaceIndex);
        uint32_t startAddress = strtoul(startAddrStr.c_str(), NULL, 16);

        // parse the end address
        String endAddrStr = args.substring(spaceIndex + 1);
        uint32_t endAddress = strtoul(endAddrStr.c_str(), NULL, 16);

        digitalWrite(FLASH_IC2_CE_n, LOW);
        delayMicroseconds(100);

        // call the function to print the hex dump
        print_hex_dump(startAddress, endAddress);

        // reset chip enable pins
        digitalWrite(FLASH_IC1_CE_n, HIGH);
        delayMicroseconds(100);
        digitalWrite(FLASH_IC2_CE_n, HIGH);
        delayMicroseconds(100);
      }
    } else if (inputString.startsWith("dp all")) {
      configure_datapins_read();
      digitalWrite(FLASH_IC1_CE_n, LOW);
      delayMicroseconds(100);
      digitalWrite(FLASH_IC2_CE_n, HIGH);
      delayMicroseconds(100);
      digitalWrite(FLASH_OE_n, LOW);
      delayMicroseconds(100);
      print_dump(0, 8388608);
      delayMicroseconds(500);
      digitalWrite(FLASH_IC1_CE_n, HIGH);
      delayMicroseconds(100);
      digitalWrite(FLASH_IC2_CE_n, HIGH);
      delay(5);

      digitalWrite(FLASH_IC1_CE_n, HIGH);
      delayMicroseconds(100);
      digitalWrite(FLASH_IC2_CE_n, LOW);
      delayMicroseconds(100);
      print_dump(0, 8388608);
      delayMicroseconds(500);
      digitalWrite(FLASH_IC1_CE_n, HIGH);
      delayMicroseconds(100);
      digitalWrite(FLASH_IC2_CE_n, HIGH);
      delay(3);
    } else if (inputString.startsWith("dp1 all")) {
      configure_datapins_read();
      digitalWrite(FLASH_IC1_CE_n, LOW);
      delayMicroseconds(100);
      digitalWrite(FLASH_IC2_CE_n, HIGH);
      delayMicroseconds(100);
      digitalWrite(FLASH_OE_n, LOW);
      delayMicroseconds(100);
      print_dump(0, 8388608);
      delayMicroseconds(500);
      digitalWrite(FLASH_IC1_CE_n, HIGH);
      digitalWrite(FLASH_IC2_CE_n, HIGH);
      delay(3);
    } else if (inputString.startsWith("dp2 all")) {
      configure_datapins_read();
      digitalWrite(FLASH_IC1_CE_n, HIGH);
      delayMicroseconds(100);
      digitalWrite(FLASH_IC2_CE_n, LOW);
      delayMicroseconds(100);
      digitalWrite(FLASH_OE_n, LOW);
      delayMicroseconds(100);
      print_dump(0, 8388608);
      delayMicroseconds(500);
      digitalWrite(FLASH_IC1_CE_n, HIGH);
      digitalWrite(FLASH_IC2_CE_n, HIGH);
      delay(3);
    } else if (inputString.startsWith("crc all")) {
      configure_datapins_read();
      digitalWrite(FLASH_OE_n, LOW);
      delayMicroseconds(100);
      SerialUSB.println("Calculating CRC32, this might take a while. Be patient...");
      SerialUSB.println("Calculating checksum for IC 1 of 2:");
      digitalWrite(FLASH_IC1_CE_n, LOW);
      delayMicroseconds(100);
      uint32_t crc32 = INITIAL_VALUE;
      crc32 = calc_crc32(0, 8388608, crc32);
      digitalWrite(FLASH_IC1_CE_n, HIGH);
      digitalWrite(FLASH_IC2_CE_n, HIGH);
      delayMicroseconds(100);

      SerialUSB.print("CRC32 IC1: 0x");
      SerialUSB.println(~crc32, HEX);

      SerialUSB.println("Calculating checksum for IC 2 of 2:");
      digitalWrite(FLASH_IC2_CE_n, LOW);
      delayMicroseconds(100);
      crc32 = calc_crc32(0, 8388608, crc32);
      digitalWrite(FLASH_IC1_CE_n, HIGH);
      digitalWrite(FLASH_IC2_CE_n, HIGH);
      delayMicroseconds(100);

      crc32 = ~crc32;
      SerialUSB.print("CRC32 (both ICs): 0x");
      SerialUSB.println(crc32, HEX);
      SerialUSB.print("done");
    } else if (inputString.startsWith("crc1 all")) {
      configure_datapins_read();
      digitalWrite(FLASH_OE_n, LOW);
      delayMicroseconds(100);
      SerialUSB.println("Calculating CRC32 for IC1, this might take a while. Be patient...");
      digitalWrite(FLASH_IC1_CE_n, LOW);
      delayMicroseconds(100);
      uint32_t crc32 = INITIAL_VALUE;
      crc32 = calc_crc32(0, 8388608, crc32);
      digitalWrite(FLASH_IC1_CE_n, HIGH);
      digitalWrite(FLASH_IC2_CE_n, HIGH);
      delayMicroseconds(100);

      crc32 = ~crc32;
      SerialUSB.print("CRC32: 0x");
      SerialUSB.println(crc32, HEX);
      SerialUSB.print("done");
    } else if (inputString.startsWith("er all")) {
      chiperase(0);
      chiperase(1);

      digitalWrite(FLASH_RST_n, LOW);
      delayMicroseconds(100);
      digitalWrite(FLASH_RST_n, HIGH);
      delayMicroseconds(100);

      SerialUSB.println("done");
    } else if (inputString.startsWith("wr1 all")) {
      SerialUSB.setTimeout(25000); 

      configure_datapins_write();
      digitalWrite(FLASH_OE_n, HIGH);
      delayMicroseconds(100);
      digitalWrite(FLASH_RST_n, HIGH);
      delayMicroseconds(100);
      digitalWrite(FLASH_WP_n, HIGH);
      delayMicroseconds(100);

      digitalWrite(FLASH_IC1_CE_n, LOW);
      delayMicroseconds(100);
      digitalWrite(FLASH_IC2_CE_n, HIGH);
      delayMicroseconds(100);

      buffered_program_received_data(0);

      digitalWrite(FLASH_IC1_CE_n, HIGH);
      delayMicroseconds(100);
      digitalWrite(FLASH_IC2_CE_n, HIGH);
      delayMicroseconds(100);
    } else if (inputString.startsWith("wr all")) {
      SerialUSB.setTimeout(25000); 

      configure_datapins_write();
      digitalWrite(FLASH_OE_n, HIGH);
      delayMicroseconds(100);
      digitalWrite(FLASH_RST_n, HIGH);
      delayMicroseconds(100);
      digitalWrite(FLASH_WP_n, HIGH);
      delayMicroseconds(100);

      digitalWrite(FLASH_IC1_CE_n, LOW);
      delayMicroseconds(100);
      digitalWrite(FLASH_IC2_CE_n, HIGH);
      delayMicroseconds(100);

      buffered_program_received_data(0);
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

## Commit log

2024-03-19 Fixed a problem when programming images. Should work a lot more stable now.
    [srx-programmer.ino]
2024-03-23 Enhanced programming robustness and drastically quicker programming speeds with buffered programming. This should rarely fail now.
    [srx-programmer.ino]
